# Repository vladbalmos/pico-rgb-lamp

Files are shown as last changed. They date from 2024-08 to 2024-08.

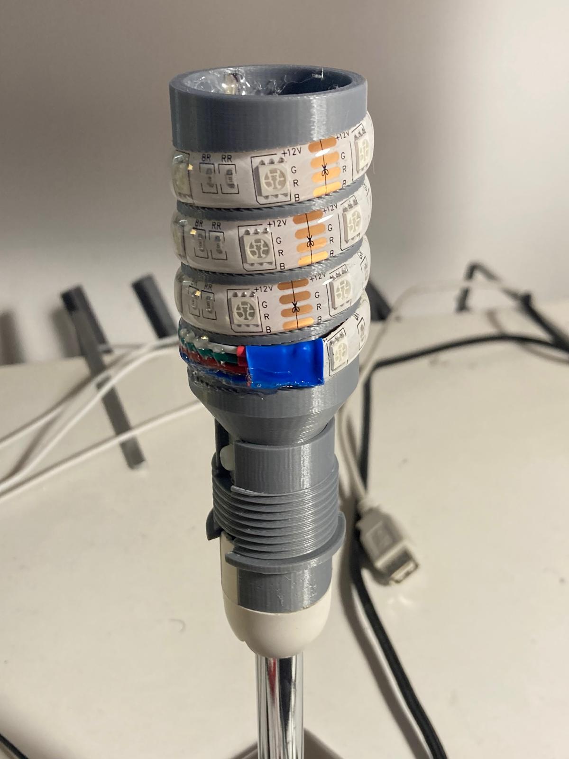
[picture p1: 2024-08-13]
hw/bulb-fixture/led_strip_fixture_assembled.jpg

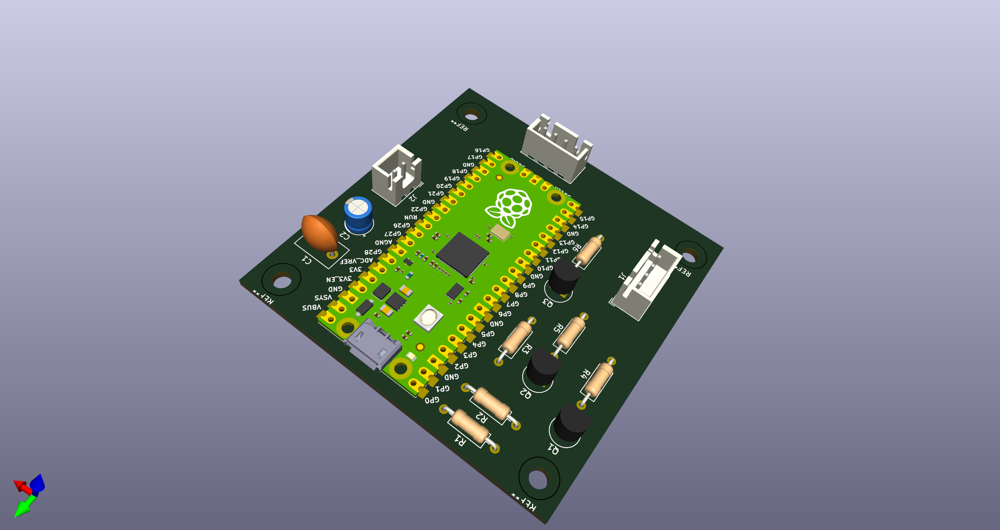
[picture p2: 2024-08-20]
hw/pcb/rgb-lamp/rgb-lamp.png

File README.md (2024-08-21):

# RGB Lamp based on RP2040

An RGB lamp powered by a Raspberry Pi Pico, offering seamless control via MQTT. Customize your lighting experience with simple commands for color changes, dynamic animations, and an audio visualizer mode.

### Features:
- **MQTT Control**
- **Color Selection**
- **Animation Selection**
- **Audio Visualizer Mode**: Requires [python-fft-streamer](https://github.com/vladbalmos/python-fft-streamer).

This project is part of my basic home automation suit and requires the [pihub](https://github.com/vladbalmos/pihub) server for remote control.

#### Demo
Demo (https://www.youtube.com/watch?v=2PfCFWdMnYo)

[View on YouTube](https://www.youtube.com/watch?v=2PfCFWdMnYo)

# System requirements

* micropython (RPI_PICO_W-20240602-v1.23.0)
* mpremote

For a complete bill of materials see the [hw/pcb](https://github.com/vladbalmos/pico-rgb-lamp/tree/main/hw/pcb/rgb-lamp) folder.

# Install

    git clone https://github.com/vladbalmos/pico-rgb-lamp
    git submodule update --init --recursive
    
# Building and flashing
Copy `device.tpl.json` to `device.json` and configure your wifi & mqtt settings. See [Device configuration](#device-configuration) for available options

## Linux

## Windows

    build.ps1 -Command build
    
# Runnig while in development

Once micropython is flashed and the source code files are copied to the device (see [Building and flashing](#building-and-flashing)) run:

    build.ps1 -Command run
    
This will reset the device first, copy the `src/` dir to the device and then call `mpremote run src/main.py`

# Device configuration

The configuration is provided in JSON format and is used to customize various aspects of the lamp, including its MQTT communication, features, and hardware setup.

## Configuration Fields

### 1. `id`
- **Type**: String
- **Description**: A unique identifier for the RGB MQTT Lamp.
- **Example**: `"RGB_MQTT_LAMP_001"`

### 2. `name`
- **Type**: String
- **Description**: The name of the RGB MQTT Lamp.
- **Example**: `"RGB MQTT Lamp"`

### 3. `ssid`
- **Type**: String
- **Description**: The SSID of the WiFi network to which the lamp should connect.

### 4. `password`
- **Type**: String
- **Description**: The password for the WiFi network.

### 5. `server`
- **Type**: String
- **Description**: The IP address or domain of the MQTT server that the lamp will communicate with.
- **Example**: `"mqtt.example.com"`

### 6. `config`
- **Type**: Object
- **Description**: Configuration related to the hardware setup and features of the lamp.

#### 6.1 `led_pins`
- **Type**: Array of integers
- **Description**: The GPIO pins used for controlling the RGB channels: [red pin, green pin, blue pin]
- **Example**: `[0, 1, 2]`

#### 6.2 `rotary_encoder_pins`
- **Type**: Array of integers
- **Description**: The GPIO pins used for the rotary encoder: [clk_pin, dt_pin]
- **Example**: `[14, 13]`

#### 6.3 `select_switch_pin`
- **Type**: Integer
- **Description**: The GPIO pin used for the select switch.
- **Example**: `15`

#### 6.4 `invert_pwm_duty_cycle`
- **Type**: Boolean
- **Description**: Whether to invert the PWM duty cycle for LED control. Usefull when using PNP / P-MOSFET drivers
- **Example**: `false`

#### 6.5 `fft_streamer`
- **Type**: Object
- **Description**: Configuration for the FFT (Fast Fourier Transform) streamer used in the audio visualizer. Not required - the lamp will automatically subscribe to the streamer mqtt channel and autoconfigure, see [python-fft-streamer](https://github.com/vladbalmos/python-fft-streamer)

##### `host`
- **Type**: String or null
- **Description**: The host for the FFT streamer.
- **Example**: `null`

##### `port`
- **Type**: Integer or null
- **Description**: The port for the FFT streamer.
- **Example**: `null`

#### 6.6 `available_colors`
- **Type**: Array of strings
- **Description**: A list of predefined colors available for selection. Colors are defined in hexadecimal format.
- **Example**: `["#ffffff", "#ff0000", "#00ff00", "#0000ff", "#ffff00", "#00ffff", "#ff00ff"]`

### 7. `features`
- **Type**: Array of objects
- **Description**: A list of features that the RGB MQTT Lamp supports.

#### 7.1 `name`
- **Type**: String
- **Description**: The name of the feature.
- **Example**: `"Change global color"`

#### 7.2 `id`
- **Type**: String
- **Description**: A unique identifier for the feature.
- **Example**: `"change_global_color"`

#### 7.3 `schema`
- **Type**: Object
- **Description**: The schema that defines the configuration options for the feature.

##### `type`
- **Type**: String
- **Description**: The data type of the feature's configuration value.
- **Example**: `"color"`, `"boolean"`, `"json"`, `"list"`

##### `default`
- **Type**: Depends on `type`
- **Description**: The default value for the feature's configuration.

###### For `change_global_color`:
- **Example**: `"#ff0000"`

###### For `enable_audio_visualizer`:
- **Example**: `false`

###### For `audio_visualizer_config`:
- **Example**: JSON object with audio visualizer settings.

###### For `animation`:
- **Example**: `"off"`

#### 7.4 `valid_values` (for `list` type)
- **Type**: Array of strings
- **Description**: A list of valid values for the feature.
- **Example**: `["off", "breathe", "wheel", "rainbow"]`

### 8. `topics`
- **Type**: Object
- **Description**: The MQTT topics used for subscription and publishing.

#### 8.1 `subscription`
- **Type**: Object
- **Description**: MQTT topics to which the lamp subscribes.

##### `manager`
- **Type**: String
- **Description**: The MQTT topic for manager requests.
- **Example**: `"acme/devices/request"`

##### `lighting`
- **Type**: String
- **Description**: The MQTT topic for lighting control.
- **Example**: `"acme/devices/lighting"`

##### `device`
- **Type**: String
- **Description**: The MQTT topic for device-specific requests.
- **Example**: `"acme/devices/lighting/name-of-device/request"`

#### 8.2 `publish`
- **Type**: Object
- **Description**: MQTT topics to which the lamp publishes messages.

##### `manager`
- **Type**: String
- **Description**: The MQTT topic for manager responses.
- **Example**: `"acme/devices/response"`

##### `device`
- **Type**: String
- **Description**: The MQTT topic for device-specific responses.
- **Example**: `"acme/devices/lighting/name-of-device/response"`

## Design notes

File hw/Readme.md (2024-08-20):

# Hardware design files

The `bulb-fixture` & `case` folders contains CAD files for a custom light bulb fixture & enclosure specifically design for a lamp I own, I doubt it would be of any use to anyone else. There's some pictures in there if you want to see what's it all about.

The PCB was designed with manual tracing in mind so the tracks are wider than they should be.

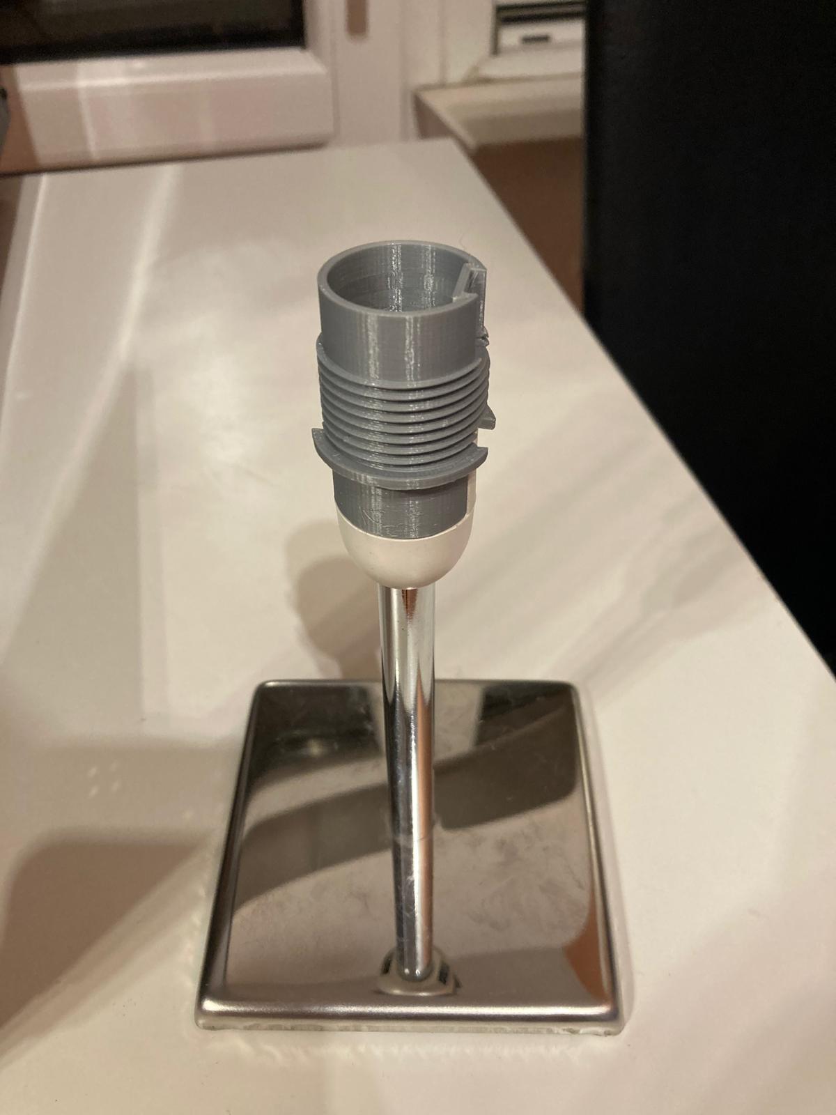
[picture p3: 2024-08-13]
hw/bulb-fixture/connector.jpg

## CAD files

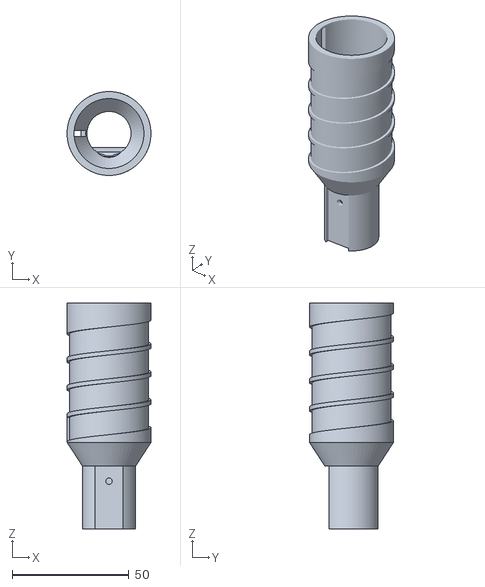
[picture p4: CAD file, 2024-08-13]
hw/bulb-fixture/led_strip_bulb_fixture.stl
36.0 x 36.0 x 97.0

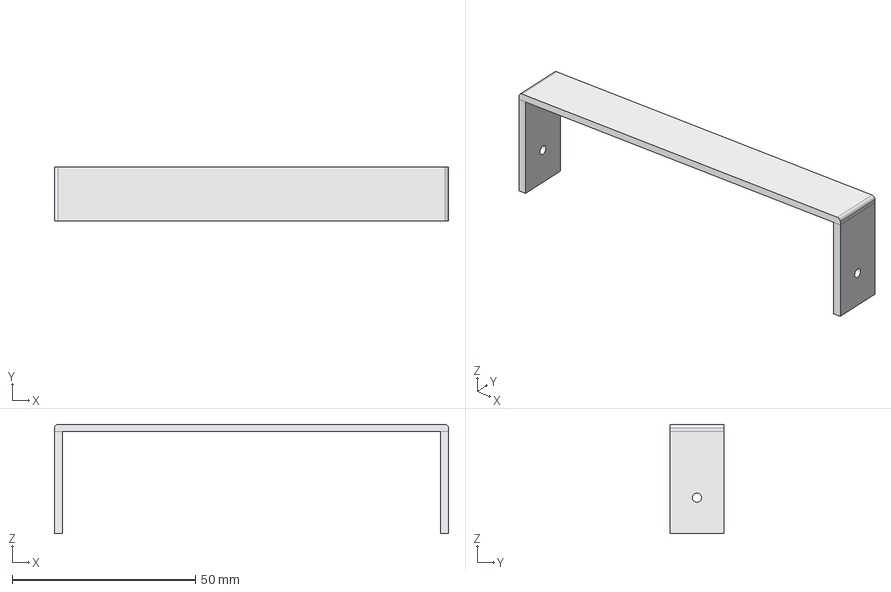
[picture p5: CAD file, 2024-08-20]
hw/case/case-Body_Top_Strap.step
107.4 x 14.9 x 29.8 mm

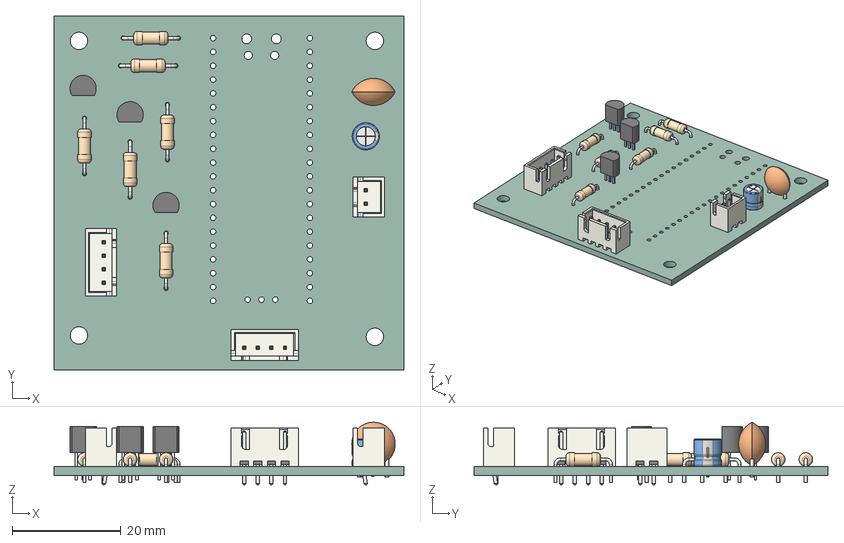
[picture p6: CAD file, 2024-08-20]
hw/pcb/rgb-lamp/rgb-lamp.step
64.3 x 65.0 x 11.5 mm
TO-92_Inline_Narrow x 3
C_Disc_D80mm_W50mm_P500mm
JST_B4B_XH_A x 2
JST_B2B_XH_A
R_Axial_DIN0207_L63mm_D25mm_P1016mm_Horizontal x 6
CP_Radial_D50mm_P250mm
rgb-lamp_PCB

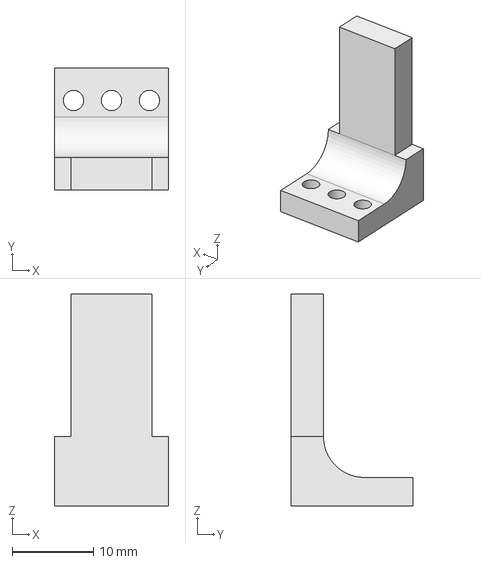
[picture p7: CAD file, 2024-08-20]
hw/case/case.FCStd
14.0 x 15.0 x 26.0 mm

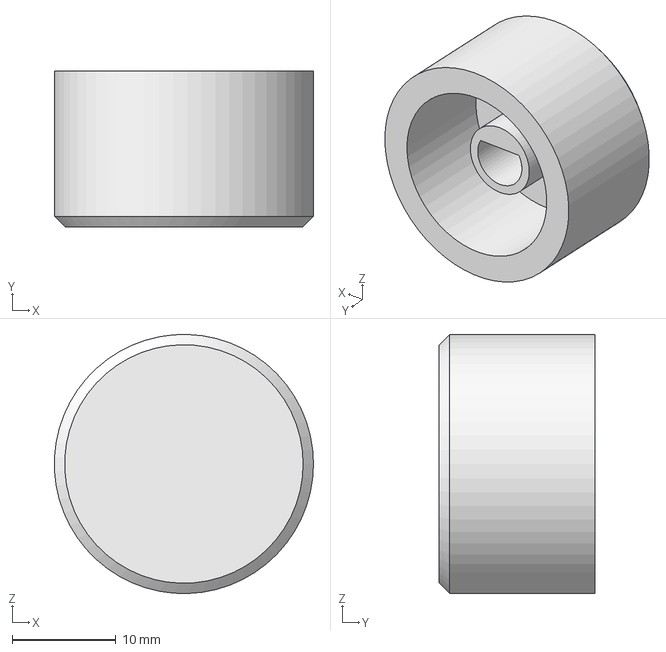
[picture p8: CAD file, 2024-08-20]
hw/case/case-Body_Encoder_Knob.step
25.0 x 15.0 x 25.0 mm

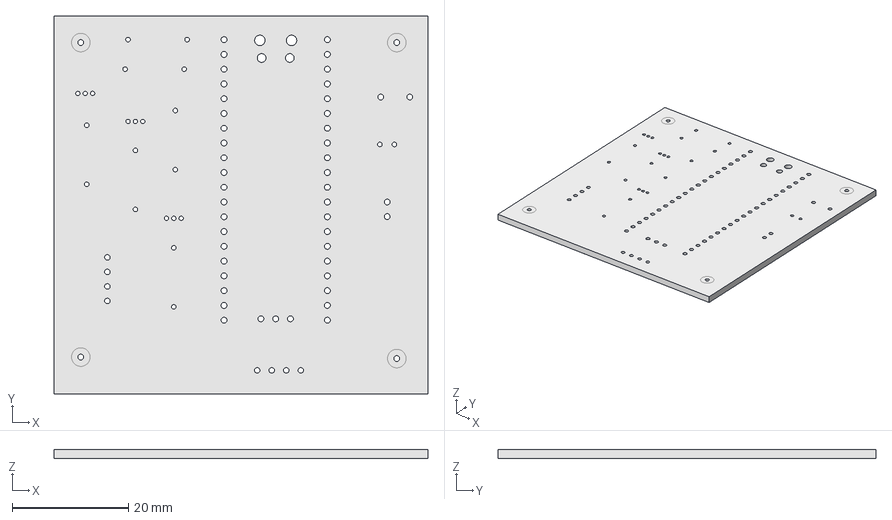
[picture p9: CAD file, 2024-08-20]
hw/case/case-Body_PCB_Drill_TemplateSketch019.step
64.3 x 65.0 x 1.60 mm

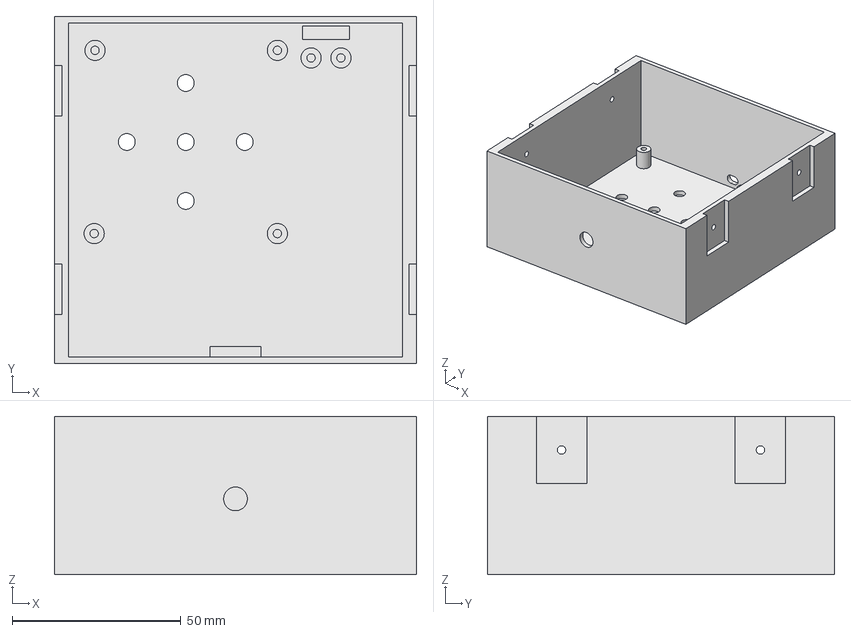
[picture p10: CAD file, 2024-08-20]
hw/case/case-Body.step
107.4 x 103.0 x 47.0 mm

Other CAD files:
hw/case/case-Body_Encoder_Stop.step
hw/case/case-Body.3mf
hw/case/case-Body_Encoder_Knob.3mf
hw/case/case-Body_Top_Strap.3mf

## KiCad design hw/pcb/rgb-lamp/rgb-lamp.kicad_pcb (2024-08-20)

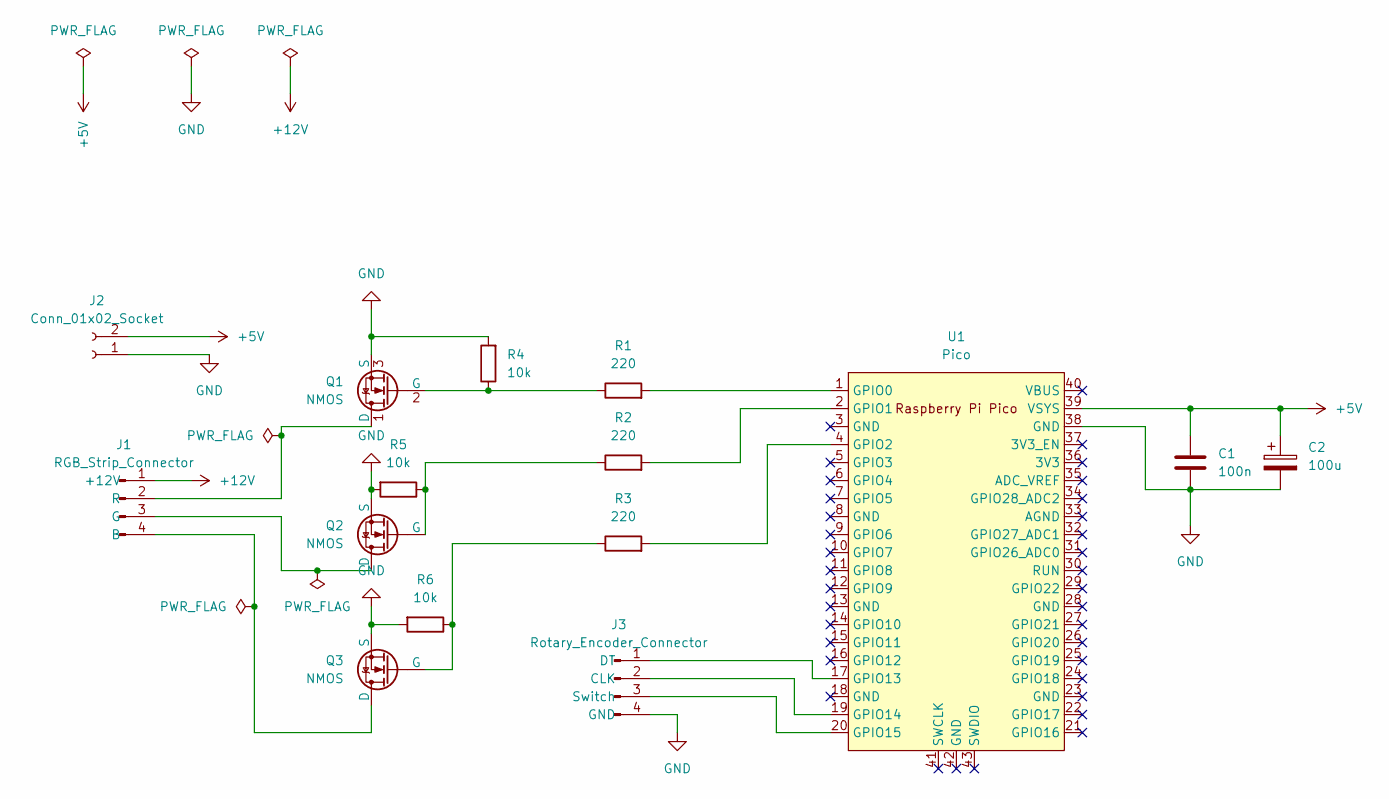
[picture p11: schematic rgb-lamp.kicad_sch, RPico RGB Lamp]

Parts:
C1: 100n; C_Disc_D8.0mm_W5.0mm_P5.00mm
C2: 100u; CP_Radial_D5.0mm_P2.50mm
J1: RGB_Strip_Connector; JST_XH_B4B-XH-A_1x04_P2.50mm_Vertical
J2: Conn_01x02_Socket; JST_XH_B2B-XH-A_1x02_P2.50mm_Vertical
J3: Rotary_Encoder_Connector; JST_XH_B4B-XH-A_1x04_P2.50mm_Vertical
Q1, Q2, Q3: NMOS; TO-92_Inline
R1, R2, R3: 220; R_Axial_DIN0207_L6.3mm_D2.5mm_P10.16mm_Horizontal
R4, R5, R6: 10k; R_Axial_DIN0207_L6.3mm_D2.5mm_P10.16mm_Horizontal
U1: Pico; RPi_Pico_SMD_TH

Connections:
+5V: C1.1, C2.1, J2.2, U1.39 (VSYS)
+12V: J1.1 (+12V)
GND: C1.2, C2.2, J2.1, J3.4 (GND), Q1.3 (S), Q2.3 (S), Q3.3 (S), R4.2, R5.2, R6.2, U1.38 (GND)
unnamed: J1.4 (B), Q3.1 (D)
unnamed: J1.3 (G), Q2.1 (D)
unnamed: J1.2 (R), Q1.1 (D)
unnamed: J3.2 (CLK), U1.19 (GPIO14)
unnamed: J3.1 (DT), U1.17 (GPIO13)
unnamed: J3.3 (Switch), U1.20 (GPIO15)
unnamed: Q1.2 (G), R1.1, R4.1
unnamed: Q2.2 (G), R2.1, R5.1
unnamed: Q3.2 (G), R3.1, R6.1
unnamed: R1.2, U1.1 (GPIO0)
unnamed: R2.2, U1.2 (GPIO1)
unnamed: R3.2, U1.4 (GPIO2)

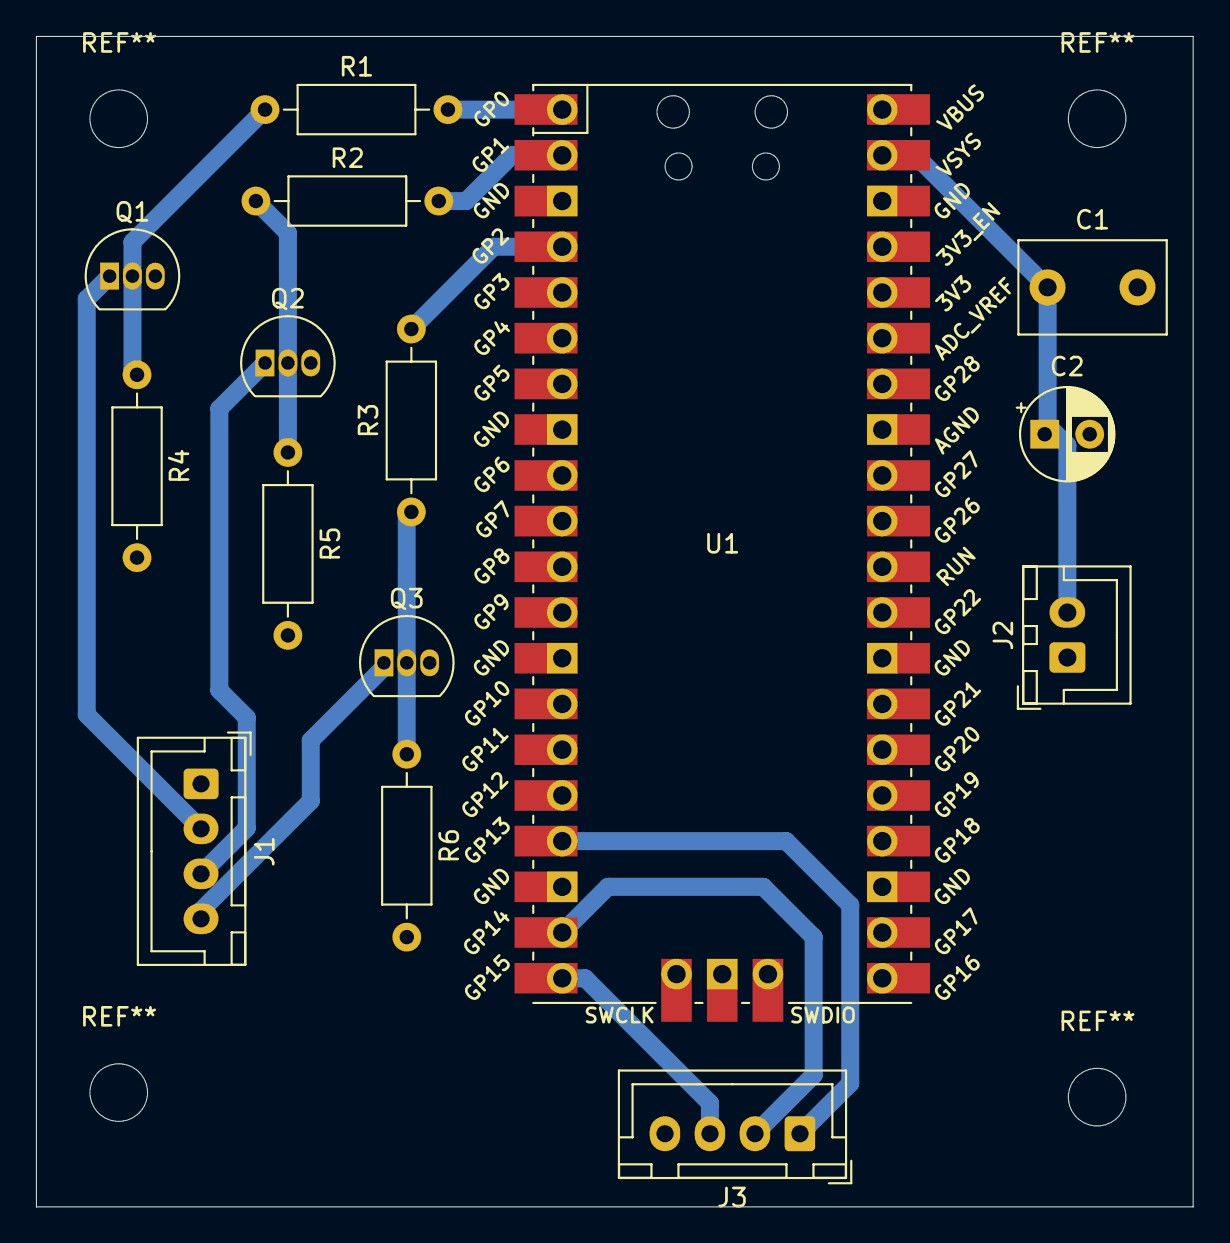
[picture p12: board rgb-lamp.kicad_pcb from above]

Board: 2 copper layers, 64.3 x 65.0 mm, 15 parts (0 on the bottom side), 14 nets.

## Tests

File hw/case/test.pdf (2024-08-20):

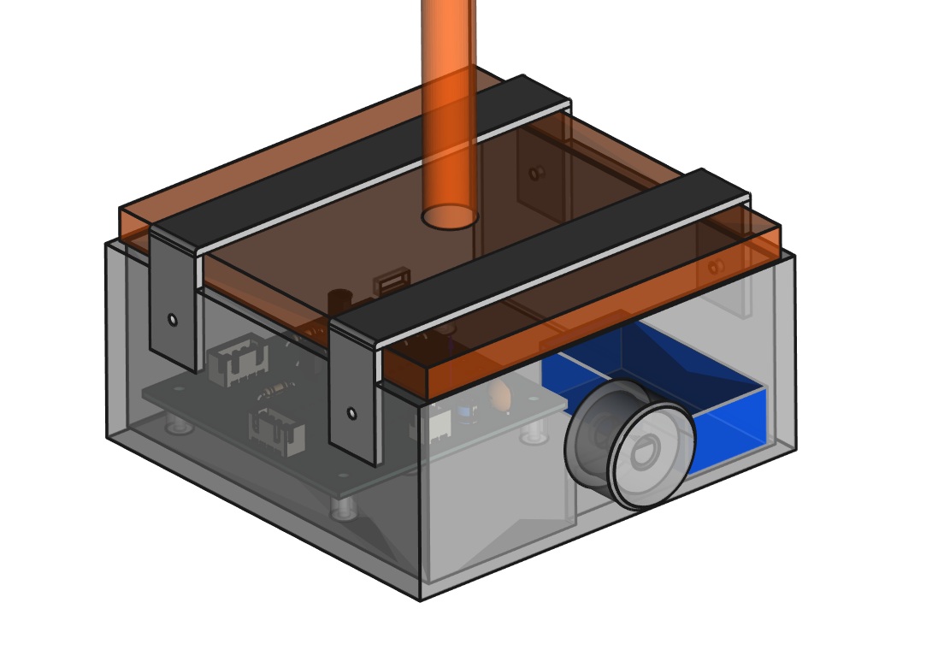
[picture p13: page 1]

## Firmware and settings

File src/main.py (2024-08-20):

import gc
import sys
import time
import json
import uasyncio as asyncio
from machine import Pin, Timer
from elastic_queue import Queue
from led import LED
from lamp import Lamp
import audio_visualizer
import device
import mqtt
import utils
from utils import log
import ui    

_TIMEOUT_MS = const(500)

audio_visualizer_task = None

UI_MENU_SELECT_COLOR = const(0)
UI_MENU_SELECT_ANIMATION = const(1)
UI_MENU_ENABLE_AUDIO_VISUALIZER = const(2)

ui_menu_state = {
    "last_active_feature": None,
    "selected_menu_item": None,
    "selected_submenu_item": None,
    "cancel_menu_timer": None,
    "state_locked": False
}

def state_lock():
    ui_menu_state["state_locked"] = True

def state_unlock():
    ui_menu_state["state_locked"] = False
    
def cancel_menu(_):
    ui.change_ui_state("idle", ui.TIMEOUT, time.ticks_ms())

def enable_menu_timeout():
    cancel_menu_timeout()
    ui_menu_state["cancel_menu_timer"] = Timer(-1) # type: ignore
    ui_menu_state["cancel_menu_timer"].init(mode = Timer.ONE_SHOT, period = 60 * 1000, callback = cancel_menu)

def cancel_menu_timeout():
    if ui_menu_state["cancel_menu_timer"] is not None:
        ui_menu_state["cancel_menu_timer"].deinit()
        ui_menu_state["cancel_menu_timer"] = None

def broadcast_updates(updates):
    for (feature_id, new_value) in updates:
        if feature_id is None:
            continue
        mqtt.broadcast(feature_id, new_value)
        
def reset_ui_menu_state():
    ui_menu_state["last_active_feature"] = None
    ui_menu_state["selected_menu_item"] = None
    ui_menu_state["selected_submenu_item"] = None
    

def lighting_message(msg):
    if 'request' not in msg:
        return False
    
    if msg['request'] != 'anouncement':
        return False

    if 'sender' not in msg:
        return False
    
    if msg['sender'] != 'fft_server':
        return False
    
    if 'message' not in msg:
        return False
    
    return True
    

def valid_feature_state_update_request(msg):
    if 'request' not in msg:
        return False
        
    if msg['request'] != 'state-update':
        return False

    if 'payload' not in msg:
        return False
        
    payload = msg['payload']
    
    if 'deviceId' not in payload or 'featureId' not in payload:
        return False
        
    if payload['deviceId'] != device.get_id():
        return False
        
    return device.has_feature(payload['featureId'])

def ui_message(msg):
    if 'ui_event' not in msg:
        return False
        
    if 'action' not in msg:
        return False
        
    if 'event' not in msg:
        return False
        
    if 'current_state' not in msg:
        return False
        
    return True

async def handle_ui_event(msg, device):
    '''
    Handle UI events and change state accordingly
    '''
    current_state = msg['current_state']
    action = msg['action']
    event = msg['event']
    event_value = msg['value']
    
    try:
        active_feature_id, active_value = device.active_feature()
    except Exception as e:
        log(e)
        return
    
    # Handle change states
    if action == 'change_state':

        if event_value == 'idle':
            state_unlock()
            # State changed to "idle"
            cancel_menu_timeout()

            if event == ui.KEY_DOWN_LP or event == ui.TIMEOUT:
                # menu section was cancelled, go back to last active feature
                if ui_menu_state["last_active_feature"] is not None:
                    feature_id, state = ui_menu_state["last_active_feature"] # type: ignore
                    device.update_features({"featureId": feature_id, "state": state})
                    
                    if feature_id == "enable_audio_visualizer" and state == 1:
                        enable_audio_visualizer(device.config("fft_streamer"))
                reset_ui_menu_state()

            # reset encoder
            ui.set_encoder_range()
            return
        
        if event_value == "menu":
            state_lock()
            # Entered main menu
            enable_menu_timeout()
            ui_menu_state["last_active_feature"] = (active_feature_id, active_value) # type: ignore
            disable_audio_visualizer()

            if active_feature_id == "change_global_color":
                encoder_value = UI_MENU_SELECT_COLOR
                device.flash_color("#ffffff")
            if active_feature_id == "animation":
                encoder_value = UI_MENU_SELECT_ANIMATION
                device.flash_color("#ff0000")
            if active_feature_id == "enable_audio_visualizer":
                encoder_value = UI_MENU_ENABLE_AUDIO_VISUALIZER
                device.flash_color("#00ff00")
                
            ui_menu_state["selected_menu_item"] = encoder_value # type: ignore
            ui.set_encoder_range(min_val = UI_MENU_SELECT_COLOR, max_val = UI_MENU_ENABLE_AUDIO_VISUALIZER, incr = 1, value = encoder_value)
            return
        
        if event_value == "submenu":
            # Entered submenu
            enable_menu_timeout()
            if ui_menu_state["selected_menu_item"] == UI_MENU_SELECT_COLOR:
                available_colors = device.config("available_colors")
                color_index = None
                if active_feature_id == "change_global_color":
                    color_index = utils.color_index_of(available_colors, active_value)
                else:
                    color_index = 0

                if color_index is None:
                    color_index = 0
                ui.set_encoder_range(min_val = 0, max_val = len(available_colors) - 1, incr = 1, value = color_index)

                device.flash_color(available_colors[color_index], framerate = 8)
                
            if ui_menu_state["selected_menu_item"] == UI_MENU_SELECT_ANIMATION:
                animation_schema = device.get_schema("animation")
                animations = [name for name in animation_schema["valid_values"] if name != 'off']
                
                animation_index = None
                if active_feature_id == "animation":
                    try:
                        animation_index = animations.index(active_value)
                    except ValueError:
                        animation_index = 0
                else:
                    animation_index = 0
                    
                if animation_index is None:
                    animation_index = 0

                device.demo_animation(animations[animation_index], color = '#00ff00')
                
            if ui_menu_state["selected_menu_item"] == UI_MENU_ENABLE_AUDIO_VISUALIZER:
                result = device.update_features({"featureId": "enable_audio_visualizer", "state": 1})
                disable_audio_visualizer()
                enable_audio_visualizer(device.config("fft_streamer"))

                broadcast_updates(result)
                # This feature doesn't have a submenu, so we go back to "idle"
                ui.change_ui_state("idle", "*", time.ticks_ms())
            return


        if event_value == "select":
            # Selected a submenu item
            if ui_menu_state["selected_menu_item"] == UI_MENU_SELECT_COLOR:
                new_color = device.config("available_colors")[ui_menu_state["selected_submenu_item"]]
                result = device.update_features({"featureId": "change_global_color", "state": new_color})
                broadcast_updates(result)

            if ui_menu_state["selected_menu_item"] == UI_MENU_SELECT_ANIMATION:
                animation_schema = device.get_schema("animation")
                animations = [name for name in animation_schema["valid_values"] if name != 'off']
                animation = animations[ui_menu_state["selected_submenu_item"]]  # type: ignore
                result = device.update_features({"featureId": "animation", "state": animation})
                broadcast_updates(result)
            return
        
    # Handle state updates
    if current_state == 'idle':
        # Handle the "idle" state
        if active_feature_id == 'change_global_color':
            if action == 'update' and (event == ui.SELECT_NEXT or event == ui.SELECT_PREV):
                new_color = utils.rgb_to_hex(utils.change_brightness(active_value, event_value))
                result = device.update_features({"featureId": "change_global_color", "state": new_color})
                broadcast_updates(result)
        return
        
        
    if current_state == 'menu':
        enable_menu_timeout()
        # Handle the "menu" state
        if action == "update" and (event == ui.SELECT_NEXT or event == ui.SELECT_PREV):
            if event_value == UI_MENU_SELECT_COLOR:
                device.flash_color("#ffffff")
            if event_value == UI_MENU_SELECT_ANIMATION:
                device.flash_color("#ff0000")
            if event_value == UI_MENU_ENABLE_AUDIO_VISUALIZER:
                device.flash_color("#00ff00")

            ui_menu_state["selected_menu_item"] = event_value # type: ignore
        return
    
    if current_state == 'submenu':
        enable_menu_timeout()
        if action == "update" and (event == ui.SELECT_NEXT or event == ui.SELECT_PREV):
            if ui_menu_state["selected_menu_item"] == UI_MENU_SELECT_COLOR:
                try:
                    new_color = device.config("available_colors")[event_value]
                    device.flash_color(new_color, framerate = 8)
                    ui_menu_state["selected_submenu_item"] = event_value # type: ignore
                except KeyError as e:
                    log("Unknown color index", event_value, "Available colors", device.config("available_colors"))
                    
            if ui_menu_state["selected_menu_item"] == UI_MENU_SELECT_ANIMATION:
                animation_schema = device.get_schema("animation")
                animations = [name for name in animation_schema["valid_values"] if name != 'off']
                try:
                    animation = animations[event_value]
                    device.demo_animation(animation, color = '#00ff00')
                    ui_menu_state["selected_submenu_item"] = event_value # type: ignore
                except KeyError as e:
                    log("Unknown animation index", event_value, "Available animations", animations)
            return

async def handle_messages(msg_queue, device):
    global audio_visualizer_task
    while True:
        msg = await msg_queue.get()
        # log("Received message")
        # log(msg)
        
        if ui_message(msg):
            await handle_ui_event(msg, device)
            continue
        
        if valid_feature_state_update_request(msg):
            if ui_menu_state["state_locked"]:
                log("Menu mode, skip message")
                continue
            
            updates = device.update_features(msg["payload"])
            disable_audio_visualizer()

            for feature_update in updates:
                feature, value = feature_update
                
                if feature == 'enable_audio_visualizer' and value == 1:
                    enable_audio_visualizer(device.config("fft_streamer"))
                    
                if feature == 'audio_visualizer_config':
                    audio_visualizer_enabled = device.get("enable_audio_visualizer")
                    if audio_visualizer_enabled == 1:
                        enable_audio_visualizer(device.config("fft_streamer"))

            broadcast_updates(updates)
                    
        if lighting_message(msg):
            message = msg['message']

            if "address" in message:
                address = message["address"]
                
                if "host" in address and "port" in address:
                    host = address["host"]
                    port = address["port"]
                    log(f"FFT Stream is at {host}:{port}")
                    device.config({"fft_streamer": {"host": host, "port": port}})
                    continue
        
async def handle_mqtt_state_changes(mqtt_state_queue):
    while True:
        state = await mqtt_state_queue.get()
        log("MQTT state", state)
        
def disable_audio_visualizer():
    global audio_visualizer_task    
            
    if audio_visualizer_task is not None:
        audio_visualizer_task.cancel()
        audio_visualizer_task = None

def enable_audio_visualizer(config):
    global audio_visualizer_task    
                
    fft_stream_host = config.get("host", None)
    fft_stream_port = config.get("port", None)

    if type(fft_stream_host) is not str or len(fft_stream_host) == 0 or type(fft_stream_port) is not int or fft_stream_port < 1:
        log("Invalid FFT Stream configuration")
        return
    
    audio_visualizer_task = asyncio.create_task(audio_visualizer.run(fft_stream_host, fft_stream_port, device))

async def main():
    status_led = Pin('LED', Pin.OUT)
    LEDs = []
    
    msg_queue = Queue(8)
    mqtt_state_queue = Queue(8)

    with open("device.json", 'r') as device_config_file:
        contents = device_config_file.read()
        device_config = json.loads(contents)
        
    config = device_config["config"]
    ui.init(msg_queue, config)

    led_pins = config["led_pins"]
    for rgb_pins in led_pins:
        led = LED(Pin(rgb_pins[0]), Pin(rgb_pins[1]), Pin(rgb_pins[2]), invert_duty_cycle = config["invert_pwm_duty_cycle"])
        LEDs.append(led)
        
    lamp = Lamp(LEDs)
    
    state = device.init(lamp, device_config)
        
    asyncio.create_task(mqtt.init(state, msg_queue, mqtt_state_queue))
    asyncio.create_task(handle_messages(msg_queue, device))
    asyncio.create_task(handle_mqtt_state_changes(mqtt_state_queue))
    
    if device.get("enable_audio_visualizer"):
        enable_audio_visualizer(device.config("fft_streamer"))
    
    last_gc_ms = time.ticks_ms()
    while True:
        status_led.toggle()
        now_ms = time.ticks_ms()
        elapsed_ms = time.ticks_diff(now_ms, last_gc_ms)
        
        gc_start_ms = time.ticks_ms()
        gc.collect()
        gc_duration_ms = time.ticks_diff(time.ticks_ms(), gc_start_ms)
        gc_duration_ms = 0

        if elapsed_ms > 5000:
            last_gc_ms = now_ms
            log("RAM free %d alloc %d. GC Duration %d"  % (gc.mem_free(), gc.mem_alloc(), gc_duration_ms))
        await asyncio.sleep_ms(_TIMEOUT_MS)

def handle_exception(_, context):
    sys.print_exception(context["exception"]) # type: ignore
    sys.exit()

if __name__ == '__main__':
    # utils.DEBUG = False
    loop = asyncio.get_event_loop()
    loop.set_exception_handler(handle_exception)
    asyncio.run(main())
    mqtt.disconnect()
    asyncio.new_event_loop()

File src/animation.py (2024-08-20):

from collections import deque
import utils
from machine import Timer
import random

_FRAME_RATE = const(60)


class Animation:
    def __init__(self, leds, duration_s = 5.0):
        self._leds = leds
        self._timer = None
        self._duration_s = duration_s
        self._steps = duration_s * _FRAME_RATE
        self._current_step = 1
        self._framerate = _FRAME_RATE
    
    def stop(self):
        if self._timer:
            self._timer.deinit()
            self._timer = None
            
    def is_running(self):
        return self._timer is not None

    def start(self):
        if not len(self._leds):
            return
        
        if self._leds[0].color is None:
            return

        self._timer = Timer(-1)
        self._timer.init(mode = Timer.PERIODIC, freq = self._framerate, callback = self._update)
        
    def _update(self, _):
        # Implement in child class
        pass
    
class NoAnimation(Animation):
    
    def __init__(self, leds, duration_s = 5.0):
        super().__init__(leds, duration_s)
        
    def start(self):
        pass
    
    def stop(self):
        pass
        
class TransitionAnimation(Animation):

    def __init__(self, leds, from_color, to_color, duration_s = 5.0):
        super().__init__(leds, duration_s)
        self._from_color = from_color
        self._to_color = to_color
        self._dr = (to_color[0] - from_color[0]) / self._steps
        self._dg = (to_color[1] - from_color[1]) / self._steps
        self._db = (to_color[2] - from_color[2]) / self._steps
        
    def _update(self, _):
        from_color = self._from_color
        steps = self._steps
        leds = self._leds
        
        dr = self._dr
        dg = self._dg
        db = self._db

        r = from_color[0] + self._current_step * dr
        g = from_color[1] + self._current_step * dg
        b = from_color[2] + self._current_step * db
        
        
        for _led in leds:
            _led.set_color((round(r), round(g), round(b)))

        self._current_step += 1
        if self._current_step > steps:
            super().stop()
        
        
class RainbowAnimation(Animation):
    def __init__(self, leds, duration_s = 5, color = None):
        super().__init__(leds, duration_s)
        self._current_color_index = 0
        self._current_animation = None
        self._rainbow_colors = [
            (255, 0, 0), # red 
            (255, 127, 0), # orange 
            (255, 255, 0), # yellow 
            (0, 255, 0), # green 
            (0, 0, 255), # blue 
            (75, 0, 130), # indigo 
            (148, 0, 211) # violet 
        ]
        
    def start(self):
        self._timer = Timer(-1)
        self._timer.init(mode = Timer.PERIODIC, period = int(self._duration_s * 1000), callback = self._update)
        self._update(None)
    
    def stop(self):
        if self._current_animation:
            self._current_animation.stop()
            self._current_animation = None
        
        if self._timer:
            self._timer.deinit()
            self._timer = None
            
    def _update(self, _):
        if self._current_animation:
            self._current_animation.stop()
            
        rainbow_colors = self._rainbow_colors

        from_color = rainbow_colors[self._current_color_index]
        
        if self._current_color_index == len(rainbow_colors) - 1:
            to_color = rainbow_colors[0]
            self._current_color_index = 0
        else:
            to_color = rainbow_colors[self._current_color_index + 1]
            self._current_color_index += 1
            
        self._current_animation = TransitionAnimation(self._leds, from_color, to_color, self._duration_s)
        self._current_animation.start()

        
class BreatheAnimation(Animation):

    def __init__(self, leds, duration_s = 5, color = None):
        super().__init__(leds, duration_s)
        self._brighter = False
        if color:
            color = utils.convert_color(color)
        else:
            color = utils.maximize_brightness(self._leds[0].color)

        self._starting_r, self._starting_g, self._starting_b = color
        self._min_brightness = 0.05
        
    def _update(self, _):
        leds = self._leds
        steps = self._steps
        min_brightness = self._min_brightness
        starting_r = self._starting_r
        starting_g = self._starting_g
        starting_b = self._starting_b

        if self._current_step > steps:
            self._current_step = 1
            if not self._brighter:
                self._brighter = True
            else:
                self._brighter = False

        if not self._brighter:
            dim_factor = max(min_brightness, 1 - self._current_step / steps)
        else:
            dim_factor = max(min_brightness, self._current_step / steps)
        
        r = starting_r * dim_factor
        g = starting_g * dim_factor
        b = starting_b * dim_factor
        
        self._current_step += 1
        
        for _led in leds:
            _led.set_color((round(r), round(g), round(b)))

class WheelAnimation(Animation):

    def __init__(self, leds, duration_s = 60, color = None):
        super().__init__(leds, duration_s)
        if color:
            color = utils.convert_color(color)
        else:
            color = utils.maximize_brightness(self._leds[0].color)

        self._h, self._s, self._v = utils.rgb_to_hsv(*color)

    def _update(self, _):
        leds = self._leds
        steps = self._steps
        self._h += 360 / steps
        
        s = self._s
        v = self._v
        
        if self._h > 360:
            self._h = 0
            
        r, g, b = utils.hsv_to_rgb(self._h, s, v)

        for _led in leds:
            _led.set_color((round(r), round(g), round(b)))
            
class FlashColorAnimation(Animation):
    
    def __init__(self, leds, framerate = 2, color = '#ffffff'):
        super().__init__(leds)
        self._r, self._g, self._b = utils.convert_color(color)
        self._framerate = framerate
        self._state = False
        
    def _update(self, _):
        if self._state:
            color = (0, 0, 0)
            self._state = False
        else:
            color = (self._r, self._g, self._b)
            self._state = True

        for _led in self._leds:
            _led.set_color((color))
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

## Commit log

2024-08-11 Add rotary encoder lib
2024-08-12 ADd support for UI using rotary encoder and microswitch
2024-08-13 Alpha version finished
    [led_strip_bulb_fixture.stl]
2024-08-13 Add schematic and pcb design
    [rgb-lamp.kicad_pcb, rgb-lamp.kicad_sch]
2024-08-20 Add more docs
    [case-Body.3mf, case-Body.step, case-Body_Encoder_Knob.3mf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]
